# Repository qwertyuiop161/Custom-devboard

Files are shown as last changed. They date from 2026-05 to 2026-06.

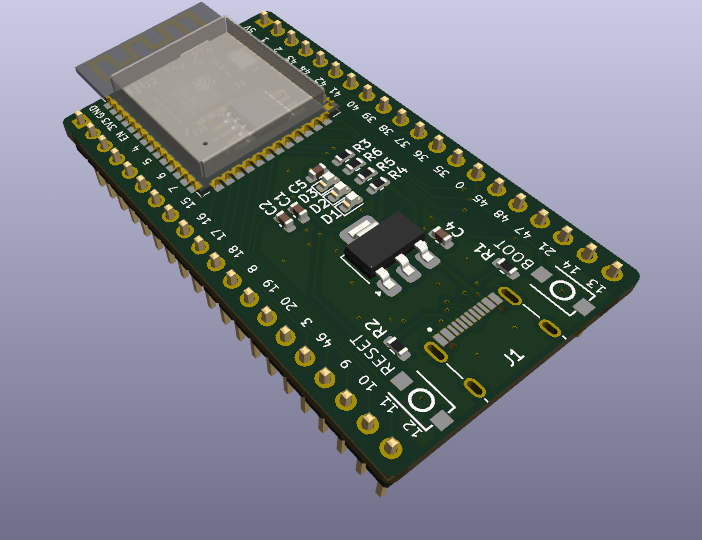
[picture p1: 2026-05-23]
images/3d model front.png

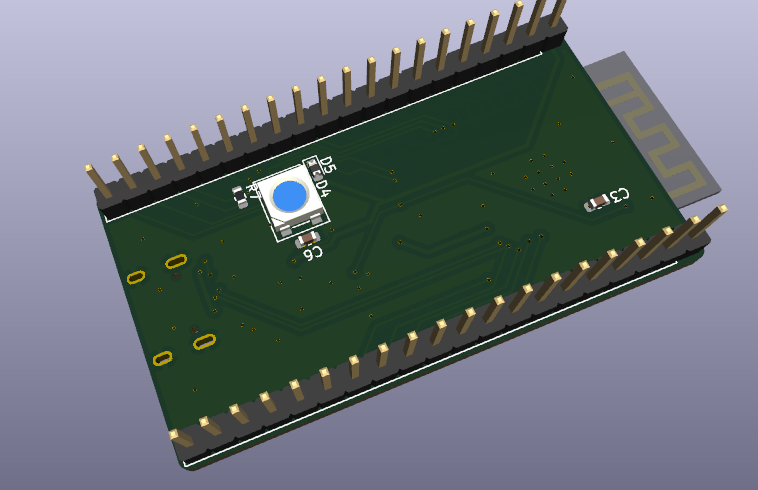
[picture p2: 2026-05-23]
images/3d model back.png

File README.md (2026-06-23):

##Description

This is a custom devboard made with an ESP32-S3-WROOM-1 module using the preinstalled firmware. It uses a usb controller and a usb C port, with 5 main capacitors and 6 main resistors, along with 3 leds. the back (because im not good enough to have it all one sided YET (still learning (wow double paren (WOW QUAD PAREN)))) hsa an addressable LES with 2 more resistors and another capacitors.
I choose the ESP chip because of its power compared to arduino, WIFI and bluetooth capability, ease of wiring, and use of use. It has 40 pins, with 30 usable GPIO i think; also just wanted to mention that semicolon was a typo its just kinda funna that im so used to java and C that i accidentally end every sentence in typing with semicolon (even accidentally did iton this before correcting).

##Images:

###Schematic image:

Image of schematic:
<br>

schematic

###PCB images:

PCB full
<br>

pcb full

PCB pads and zones
<br>

pcb pads and zones

PCB tracks and vias
<br>

pcb tracks and vias

###3D Model images:

3D model front
<br>

3d model front

3D model back
<br>

3d model back

###BOM image:

BOM
<br>



###Bult Board:

Built Board! (sorry for low quality I have a bad camera):

WIN_20260622_18_30_54_Pro

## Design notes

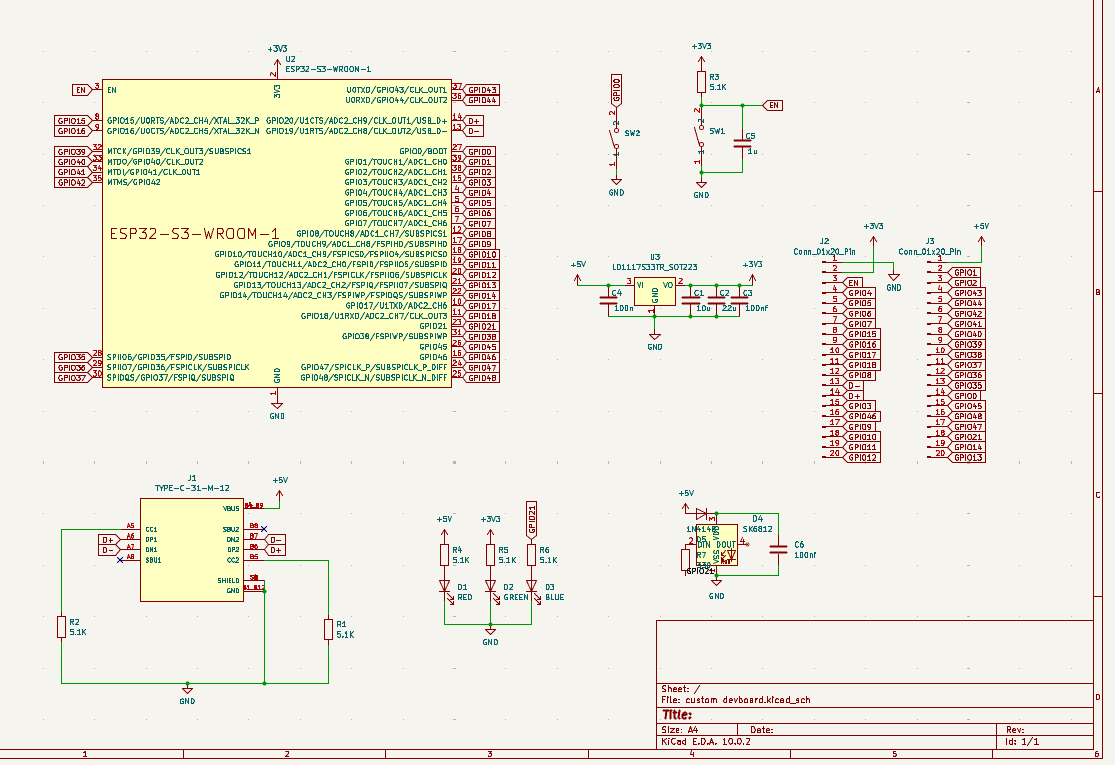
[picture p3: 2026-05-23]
images/schematic.png

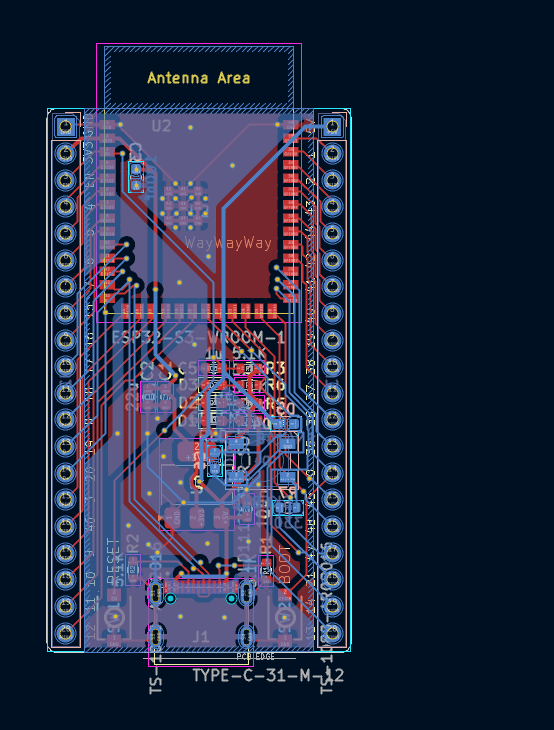
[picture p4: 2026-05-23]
images/pcb full.png

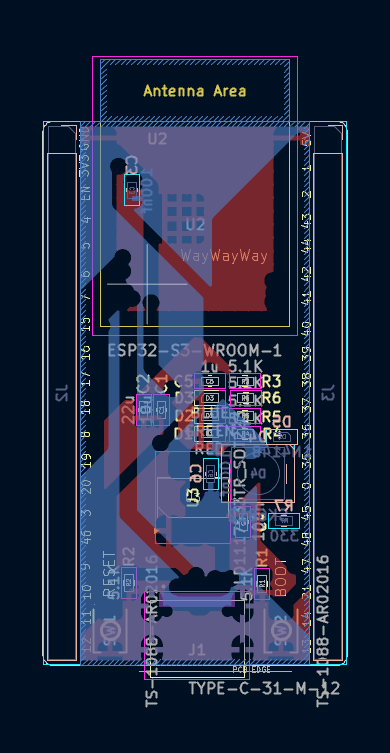
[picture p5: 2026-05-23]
images/pcb pads and zones.png

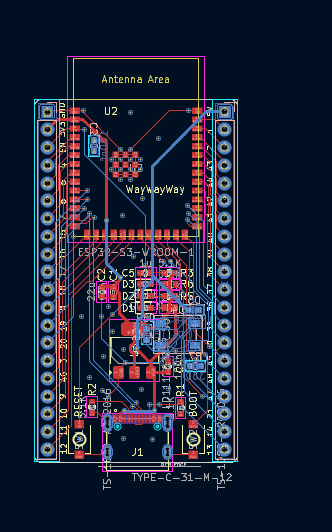
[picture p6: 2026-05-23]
images/pcb tracks and vias.png

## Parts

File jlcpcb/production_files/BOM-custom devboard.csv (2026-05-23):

Comment | Designator | Footprint | LCSC | Quantity
100n | C4 | C_0603_1608Metric | C14663 | 1
100nf | C3,C6 | C_0603_1608Metric | C1591 | 2
10u | C1 | C_0603_1608Metric | C19702 | 1
1N4148 | D5 | D_0603_1608Metric | C2972761 | 1
1u | C5 | C_0603_1608Metric | C14664 | 1
22u | C2 | C_0603_1608Metric | C2762594 | 1
330 | R7 | R_0603_1608Metric | C105881 | 1
5.1K | R1,R2,R3,R4,R5,R6 | R_0603_1608Metric | C105580 | 6
BLUE | D3 | LED_0603_1608Metric | C72041 | 1
Conn_01x20_Pin | J2,J3 | PinHeader_1x20_P2.54mm_Vertical | C7501591 | 2
ESP32-S3-WROOM-1 | U2 | ESP32-S3-WROOM-1 | C2913202 | 1
GREEN | D2 | LED_0603_1608Metric | C72043 | 1
LD1117S33TR_SOT223 | U3 | SOT-223-3_TabPin2 | C86781 | 1
RED | D1 | LED_0603_1608Metric | C2286 | 1
SK6812 | D4 | LED_SK6812_PLCC4_5.0x5.0mm_P3.2mm | C5378720 | 1
TS-1088-AR02016 | SW1,SW2 | SW-SMD_L3.9-W3.0-P4.45 | C720477 | 2
TYPE-C-31-M-12 | J1 | HRO_TYPE-C-31-M-12 | C165948 | 1

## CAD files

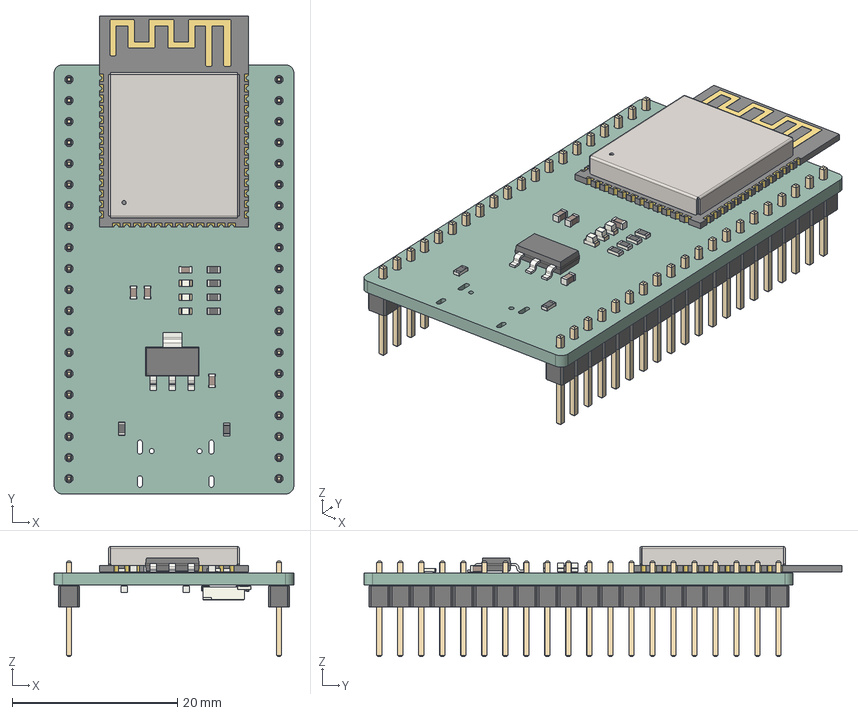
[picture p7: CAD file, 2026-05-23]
schematic and pcb and 3d model/3d.step
29.0 x 57.8 x 13.3 mm
R_0603_1608Metric x 7
LED_0603_1608Metric x 3
SOT-223
C_0603_1608Metric x 6
C0201_20210301.STEP^C0201_20210301.STEP_Submodel-C0201_part_ DesignRootModel_PCB_ESP32-S3-WROOM-1_V1(2)_PCB_ESP32-S3-WROOM-1_V1 x 14
L0201_20210301.STEP^L0201_20210301.STEP_Submodel-L0201_part_ DesignRootModel_PCB_ESP32-S3-WROOM-1_V1(2)_PCB_ESP32-S3-WROOM-1_V1 x 3
C0402_20210301.STEP^C0402_20210301.STEP_Submodel-C0402_part_ DesignRootModel_PCB_ESP32-S3-WROOM-1_V1(2)_PCB_ESP32-S3-WROOM-1_V1
R0201_20210301.STEP^R0201_20210301.STEP_Submodel-R0201_part_ DesignRootModel_PCB_ESP32-S3-WROOM-1_V1(2)_PCB_ESP32-S3-WROOM-1_V1 x 8
trace_1^Submodel-MINI-ANT-TYPEB_668419613_part_DesignRootModel_PCB_ ESP32-S3-WROOM-1_V1(2)_PCB_ESP32-S3-WROOM-1_V1
DFN1006.STEP^DFN1006.STEP_Submodel-SOD882_part_DesignRootModel_PCB_ ESP32-S3-WROOM-1_V1(2)_PCB_ESP32-S3-WROOM-1_V1
SOP8_rev1_20210308.STEP^SOP8_rev1_20210308.STEP_Submodel-SOP8_1P27_6P6_ part_DesignRootModel_PCB_ESP32-S3-WROOM-1_V1(2)_PCB_ESP32-S3-WROOM-1_V1
XTAL3225_20210301.STEP^XTAL3225_20210301.STEP_Submodel-XTAL3225_part_ DesignRootModel_PCB_ESP32-S3-WROOM-1_V1(2)_PCB_ESP32-S3-WROOM-1_V1
ESP32-S3_20210301.STEP^ESP32-S3_20210301.STEP_Submodel-QFN56_0P4_7_ part_DesignRootModel_PCB_ESP32-S3-WROOM-1_V1(2)_PCB_ESP32-S3-WROOM-1_V1
uid__4-128^DesignRootModel_PCB_ESP32-S3-WROOM-1_V1(2)_PCB_ ESP32-S3-WROOM-1_V1
uid__4-129^DesignRootModel_PCB_ESP32-S3-WROOM-1_V1(2)_PCB_ ESP32-S3-WROOM-1_V1
uid__4-130^DesignRootModel_PCB_ESP32-S3-WROOM-1_V1(2)_PCB_ ESP32-S3-WROOM-1_V1
uid__4-149^DesignRootModel_PCB_ESP32-S3-WROOM-1_V1(2)_PCB_ ESP32-S3-WROOM-1_V1
uid__4-150^DesignRootModel_PCB_ESP32-S3-WROOM-1_V1(2)_PCB_ ESP32-S3-WROOM-1_V1
uid__4-151^DesignRootModel_PCB_ESP32-S3-WROOM-1_V1(2)_PCB_ ESP32-S3-WROOM-1_V1
uid__4-167^DesignRootModel_PCB_ESP32-S3-WROOM-1_V1(2)_PCB_ ESP32-S3-WROOM-1_V1
uid__4-168^DesignRootModel_PCB_ESP32-S3-WROOM-1_V1(2)_PCB_ ESP32-S3-WROOM-1_V1
uid__4-169^DesignRootModel_PCB_ESP32-S3-WROOM-1_V1(2)_PCB_ ESP32-S3-WROOM-1_V1
uid__1-279^DesignRootModel_PCB_ESP32-S3-WROOM-1_V1(2)_PCB_ ESP32-S3-WROOM-1_V1
uid__1-280^DesignRootModel_PCB_ESP32-S3-WROOM-1_V1(2)_PCB_ ESP32-S3-WROOM-1_V1
uid__1-292^DesignRootModel_PCB_ESP32-S3-WROOM-1_V1(2)_PCB_ ESP32-S3-WROOM-1_V1
uid__1-298^DesignRootModel_PCB_ESP32-S3-WROOM-1_V1(2)_PCB_ ESP32-S3-WROOM-1_V1
uid__1-299^DesignRootModel_PCB_ESP32-S3-WROOM-1_V1(2)_PCB_ ESP32-S3-WROOM-1_V1
uid__1-300^DesignRootModel_PCB_ESP32-S3-WROOM-1_V1(2)_PCB_ ESP32-S3-WROOM-1_V1
uid__1-301^DesignRootModel_PCB_ESP32-S3-WROOM-1_V1(2)_PCB_ ESP32-S3-WROOM-1_V1
uid__1-304^DesignRootModel_PCB_ESP32-S3-WROOM-1_V1(2)_PCB_ ESP32-S3-WROOM-1_V1
uid__1-305^DesignRootModel_PCB_ESP32-S3-WROOM-1_V1(2)_PCB_ ESP32-S3-WROOM-1_V1
uid__1-308^DesignRootModel_PCB_ESP32-S3-WROOM-1_V1(2)_PCB_ ESP32-S3-WROOM-1_V1
uid__1-310^DesignRootModel_PCB_ESP32-S3-WROOM-1_V1(2)_PCB_ ESP32-S3-WROOM-1_V1
uid__1-311^DesignRootModel_PCB_ESP32-S3-WROOM-1_V1(2)_PCB_ ESP32-S3-WROOM-1_V1
uid__1-325^DesignRootModel_PCB_ESP32-S3-WROOM-1_V1(2)_PCB_ ESP32-S3-WROOM-1_V1
uid__1-334^DesignRootModel_PCB_ESP32-S3-WROOM-1_V1(2)_PCB_ ESP32-S3-WROOM-1_V1
uid__1-338^DesignRootModel_PCB_ESP32-S3-WROOM-1_V1(2)_PCB_ ESP32-S3-WROOM-1_V1
uid__1-339^DesignRootModel_PCB_ESP32-S3-WROOM-1_V1(2)_PCB_ ESP32-S3-WROOM-1_V1
uid__1-340^DesignRootModel_PCB_ESP32-S3-WROOM-1_V1(2)_PCB_ ESP32-S3-WROOM-1_V1
uid__1-343^DesignRootModel_PCB_ESP32-S3-WROOM-1_V1(2)_PCB_ ESP32-S3-WROOM-1_V1
uid__1-344^DesignRootModel_PCB_ESP32-S3-WROOM-1_V1(2)_PCB_ ESP32-S3-WROOM-1_V1
uid__1-345^DesignRootModel_PCB_ESP32-S3-WROOM-1_V1(2)_PCB_ ESP32-S3-WROOM-1_V1
uid__1-352^DesignRootModel_PCB_ESP32-S3-WROOM-1_V1(2)_PCB_ ESP32-S3-WROOM-1_V1
uid__1-354^DesignRootModel_PCB_ESP32-S3-WROOM-1_V1(2)_PCB_ ESP32-S3-WROOM-1_V1
uid__1-355^DesignRootModel_PCB_ESP32-S3-WROOM-1_V1(2)_PCB_ ESP32-S3-WROOM-1_V1
uid__1-357^DesignRootModel_PCB_ESP32-S3-WROOM-1_V1(2)_PCB_ ESP32-S3-WROOM-1_V1
uid__1-358^DesignRootModel_PCB_ESP32-S3-WROOM-1_V1(2)_PCB_ ESP32-S3-WROOM-1_V1
uid__1-359^DesignRootModel_PCB_ESP32-S3-WROOM-1_V1(2)_PCB_ ESP32-S3-WROOM-1_V1
uid__1-364^DesignRootModel_PCB_ESP32-S3-WROOM-1_V1(2)_PCB_ ESP32-S3-WROOM-1_V1
uid__1-365^DesignRootModel_PCB_ESP32-S3-WROOM-1_V1(2)_PCB_ ESP32-S3-WROOM-1_V1
uid__1-371^DesignRootModel_PCB_ESP32-S3-WROOM-1_V1(2)_PCB_ ESP32-S3-WROOM-1_V1
uid__1-375^DesignRootModel_PCB_ESP32-S3-WROOM-1_V1(2)_PCB_ ESP32-S3-WROOM-1_V1
uid__1-376^DesignRootModel_PCB_ESP32-S3-WROOM-1_V1(2)_PCB_ ESP32-S3-WROOM-1_V1
uid__1-378^DesignRootModel_PCB_ESP32-S3-WROOM-1_V1(2)_PCB_ ESP32-S3-WROOM-1_V1
uid__1-379^DesignRootModel_PCB_ESP32-S3-WROOM-1_V1(2)_PCB_ ESP32-S3-WROOM-1_V1
uid__1-380^DesignRootModel_PCB_ESP32-S3-WROOM-1_V1(2)_PCB_ ESP32-S3-WROOM-1_V1
uid__1-381^DesignRootModel_PCB_ESP32-S3-WROOM-1_V1(2)_PCB_ ESP32-S3-WROOM-1_V1
uid__1-382^DesignRootModel_PCB_ESP32-S3-WROOM-1_V1(2)_PCB_ ESP32-S3-WROOM-1_V1
uid__1-383^DesignRootModel_PCB_ESP32-S3-WROOM-1_V1(2)_PCB_ ESP32-S3-WROOM-1_V1
uid__1-384^DesignRootModel_PCB_ESP32-S3-WROOM-1_V1(2)_PCB_ ESP32-S3-WROOM-1_V1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

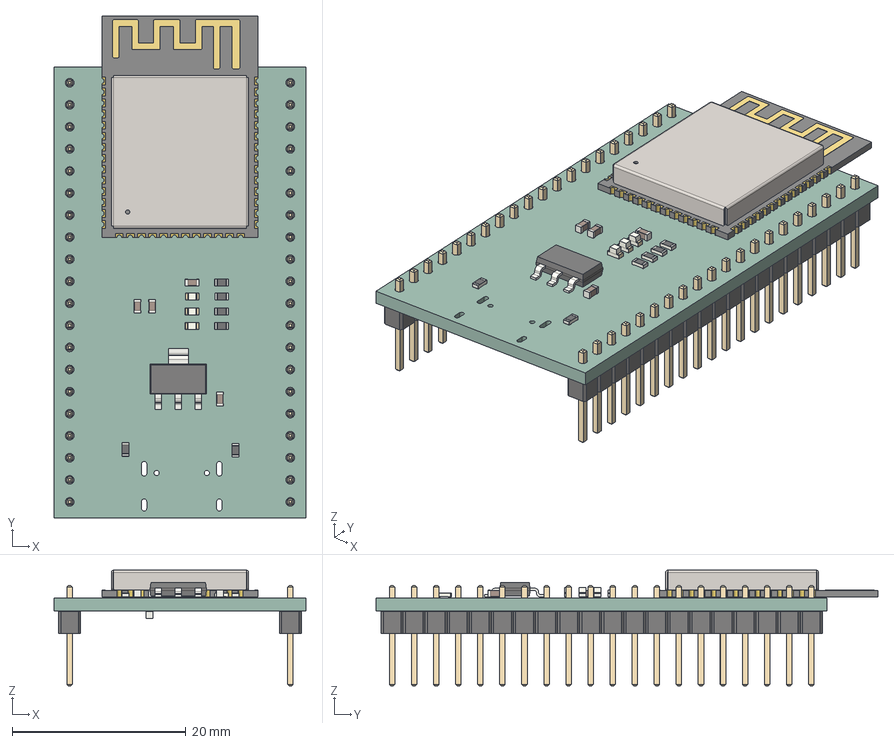
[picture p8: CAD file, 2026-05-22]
schematic and pcb and 3d model/custom devboard.step
29.0 x 57.8 x 13.3 mm
R_0603_1608Metric x 6
LED_0603_1608Metric x 3
SOT-223
C_0603_1608Metric x 5
C0201_20210301.STEP^C0201_20210301.STEP_Submodel-C0201_part_ DesignRootModel_PCB_ESP32-S3-WROOM-1_V1(2)_PCB_ESP32-S3-WROOM-1_V1 x 14
L0201_20210301.STEP^L0201_20210301.STEP_Submodel-L0201_part_ DesignRootModel_PCB_ESP32-S3-WROOM-1_V1(2)_PCB_ESP32-S3-WROOM-1_V1 x 3
C0402_20210301.STEP^C0402_20210301.STEP_Submodel-C0402_part_ DesignRootModel_PCB_ESP32-S3-WROOM-1_V1(2)_PCB_ESP32-S3-WROOM-1_V1
R0201_20210301.STEP^R0201_20210301.STEP_Submodel-R0201_part_ DesignRootModel_PCB_ESP32-S3-WROOM-1_V1(2)_PCB_ESP32-S3-WROOM-1_V1 x 8
trace_1^Submodel-MINI-ANT-TYPEB_668419613_part_DesignRootModel_PCB_ ESP32-S3-WROOM-1_V1(2)_PCB_ESP32-S3-WROOM-1_V1
DFN1006.STEP^DFN1006.STEP_Submodel-SOD882_part_DesignRootModel_PCB_ ESP32-S3-WROOM-1_V1(2)_PCB_ESP32-S3-WROOM-1_V1
SOP8_rev1_20210308.STEP^SOP8_rev1_20210308.STEP_Submodel-SOP8_1P27_6P6_ part_DesignRootModel_PCB_ESP32-S3-WROOM-1_V1(2)_PCB_ESP32-S3-WROOM-1_V1
XTAL3225_20210301.STEP^XTAL3225_20210301.STEP_Submodel-XTAL3225_part_ DesignRootModel_PCB_ESP32-S3-WROOM-1_V1(2)_PCB_ESP32-S3-WROOM-1_V1
ESP32-S3_20210301.STEP^ESP32-S3_20210301.STEP_Submodel-QFN56_0P4_7_ part_DesignRootModel_PCB_ESP32-S3-WROOM-1_V1(2)_PCB_ESP32-S3-WROOM-1_V1
uid__4-128^DesignRootModel_PCB_ESP32-S3-WROOM-1_V1(2)_PCB_ ESP32-S3-WROOM-1_V1
uid__4-129^DesignRootModel_PCB_ESP32-S3-WROOM-1_V1(2)_PCB_ ESP32-S3-WROOM-1_V1
uid__4-130^DesignRootModel_PCB_ESP32-S3-WROOM-1_V1(2)_PCB_ ESP32-S3-WROOM-1_V1
uid__4-149^DesignRootModel_PCB_ESP32-S3-WROOM-1_V1(2)_PCB_ ESP32-S3-WROOM-1_V1
uid__4-150^DesignRootModel_PCB_ESP32-S3-WROOM-1_V1(2)_PCB_ ESP32-S3-WROOM-1_V1
uid__4-151^DesignRootModel_PCB_ESP32-S3-WROOM-1_V1(2)_PCB_ ESP32-S3-WROOM-1_V1
uid__4-167^DesignRootModel_PCB_ESP32-S3-WROOM-1_V1(2)_PCB_ ESP32-S3-WROOM-1_V1
uid__4-168^DesignRootModel_PCB_ESP32-S3-WROOM-1_V1(2)_PCB_ ESP32-S3-WROOM-1_V1
uid__4-169^DesignRootModel_PCB_ESP32-S3-WROOM-1_V1(2)_PCB_ ESP32-S3-WROOM-1_V1
uid__1-279^DesignRootModel_PCB_ESP32-S3-WROOM-1_V1(2)_PCB_ ESP32-S3-WROOM-1_V1
uid__1-280^DesignRootModel_PCB_ESP32-S3-WROOM-1_V1(2)_PCB_ ESP32-S3-WROOM-1_V1
uid__1-292^DesignRootModel_PCB_ESP32-S3-WROOM-1_V1(2)_PCB_ ESP32-S3-WROOM-1_V1
uid__1-298^DesignRootModel_PCB_ESP32-S3-WROOM-1_V1(2)_PCB_ ESP32-S3-WROOM-1_V1
uid__1-299^DesignRootModel_PCB_ESP32-S3-WROOM-1_V1(2)_PCB_ ESP32-S3-WROOM-1_V1
uid__1-300^DesignRootModel_PCB_ESP32-S3-WROOM-1_V1(2)_PCB_ ESP32-S3-WROOM-1_V1
uid__1-301^DesignRootModel_PCB_ESP32-S3-WROOM-1_V1(2)_PCB_ ESP32-S3-WROOM-1_V1
uid__1-304^DesignRootModel_PCB_ESP32-S3-WROOM-1_V1(2)_PCB_ ESP32-S3-WROOM-1_V1
uid__1-305^DesignRootModel_PCB_ESP32-S3-WROOM-1_V1(2)_PCB_ ESP32-S3-WROOM-1_V1
uid__1-308^DesignRootModel_PCB_ESP32-S3-WROOM-1_V1(2)_PCB_ ESP32-S3-WROOM-1_V1
uid__1-310^DesignRootModel_PCB_ESP32-S3-WROOM-1_V1(2)_PCB_ ESP32-S3-WROOM-1_V1
uid__1-311^DesignRootModel_PCB_ESP32-S3-WROOM-1_V1(2)_PCB_ ESP32-S3-WROOM-1_V1
uid__1-325^DesignRootModel_PCB_ESP32-S3-WROOM-1_V1(2)_PCB_ ESP32-S3-WROOM-1_V1
uid__1-334^DesignRootModel_PCB_ESP32-S3-WROOM-1_V1(2)_PCB_ ESP32-S3-WROOM-1_V1
uid__1-338^DesignRootModel_PCB_ESP32-S3-WROOM-1_V1(2)_PCB_ ESP32-S3-WROOM-1_V1
uid__1-339^DesignRootModel_PCB_ESP32-S3-WROOM-1_V1(2)_PCB_ ESP32-S3-WROOM-1_V1
uid__1-340^DesignRootModel_PCB_ESP32-S3-WROOM-1_V1(2)_PCB_ ESP32-S3-WROOM-1_V1
uid__1-343^DesignRootModel_PCB_ESP32-S3-WROOM-1_V1(2)_PCB_ ESP32-S3-WROOM-1_V1
uid__1-344^DesignRootModel_PCB_ESP32-S3-WROOM-1_V1(2)_PCB_ ESP32-S3-WROOM-1_V1
uid__1-345^DesignRootModel_PCB_ESP32-S3-WROOM-1_V1(2)_PCB_ ESP32-S3-WROOM-1_V1
uid__1-352^DesignRootModel_PCB_ESP32-S3-WROOM-1_V1(2)_PCB_ ESP32-S3-WROOM-1_V1
uid__1-354^DesignRootModel_PCB_ESP32-S3-WROOM-1_V1(2)_PCB_ ESP32-S3-WROOM-1_V1
uid__1-355^DesignRootModel_PCB_ESP32-S3-WROOM-1_V1(2)_PCB_ ESP32-S3-WROOM-1_V1
uid__1-357^DesignRootModel_PCB_ESP32-S3-WROOM-1_V1(2)_PCB_ ESP32-S3-WROOM-1_V1
uid__1-358^DesignRootModel_PCB_ESP32-S3-WROOM-1_V1(2)_PCB_ ESP32-S3-WROOM-1_V1
uid__1-359^DesignRootModel_PCB_ESP32-S3-WROOM-1_V1(2)_PCB_ ESP32-S3-WROOM-1_V1
uid__1-364^DesignRootModel_PCB_ESP32-S3-WROOM-1_V1(2)_PCB_ ESP32-S3-WROOM-1_V1
uid__1-365^DesignRootModel_PCB_ESP32-S3-WROOM-1_V1(2)_PCB_ ESP32-S3-WROOM-1_V1
uid__1-371^DesignRootModel_PCB_ESP32-S3-WROOM-1_V1(2)_PCB_ ESP32-S3-WROOM-1_V1
uid__1-375^DesignRootModel_PCB_ESP32-S3-WROOM-1_V1(2)_PCB_ ESP32-S3-WROOM-1_V1
uid__1-376^DesignRootModel_PCB_ESP32-S3-WROOM-1_V1(2)_PCB_ ESP32-S3-WROOM-1_V1
uid__1-378^DesignRootModel_PCB_ESP32-S3-WROOM-1_V1(2)_PCB_ ESP32-S3-WROOM-1_V1
uid__1-379^DesignRootModel_PCB_ESP32-S3-WROOM-1_V1(2)_PCB_ ESP32-S3-WROOM-1_V1
uid__1-380^DesignRootModel_PCB_ESP32-S3-WROOM-1_V1(2)_PCB_ ESP32-S3-WROOM-1_V1
uid__1-381^DesignRootModel_PCB_ESP32-S3-WROOM-1_V1(2)_PCB_ ESP32-S3-WROOM-1_V1
uid__1-382^DesignRootModel_PCB_ESP32-S3-WROOM-1_V1(2)_PCB_ ESP32-S3-WROOM-1_V1
uid__1-383^DesignRootModel_PCB_ESP32-S3-WROOM-1_V1(2)_PCB_ ESP32-S3-WROOM-1_V1
uid__1-384^DesignRootModel_PCB_ESP32-S3-WROOM-1_V1(2)_PCB_ ESP32-S3-WROOM-1_V1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

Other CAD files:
schematic and pcb and 3d model/3d.stl

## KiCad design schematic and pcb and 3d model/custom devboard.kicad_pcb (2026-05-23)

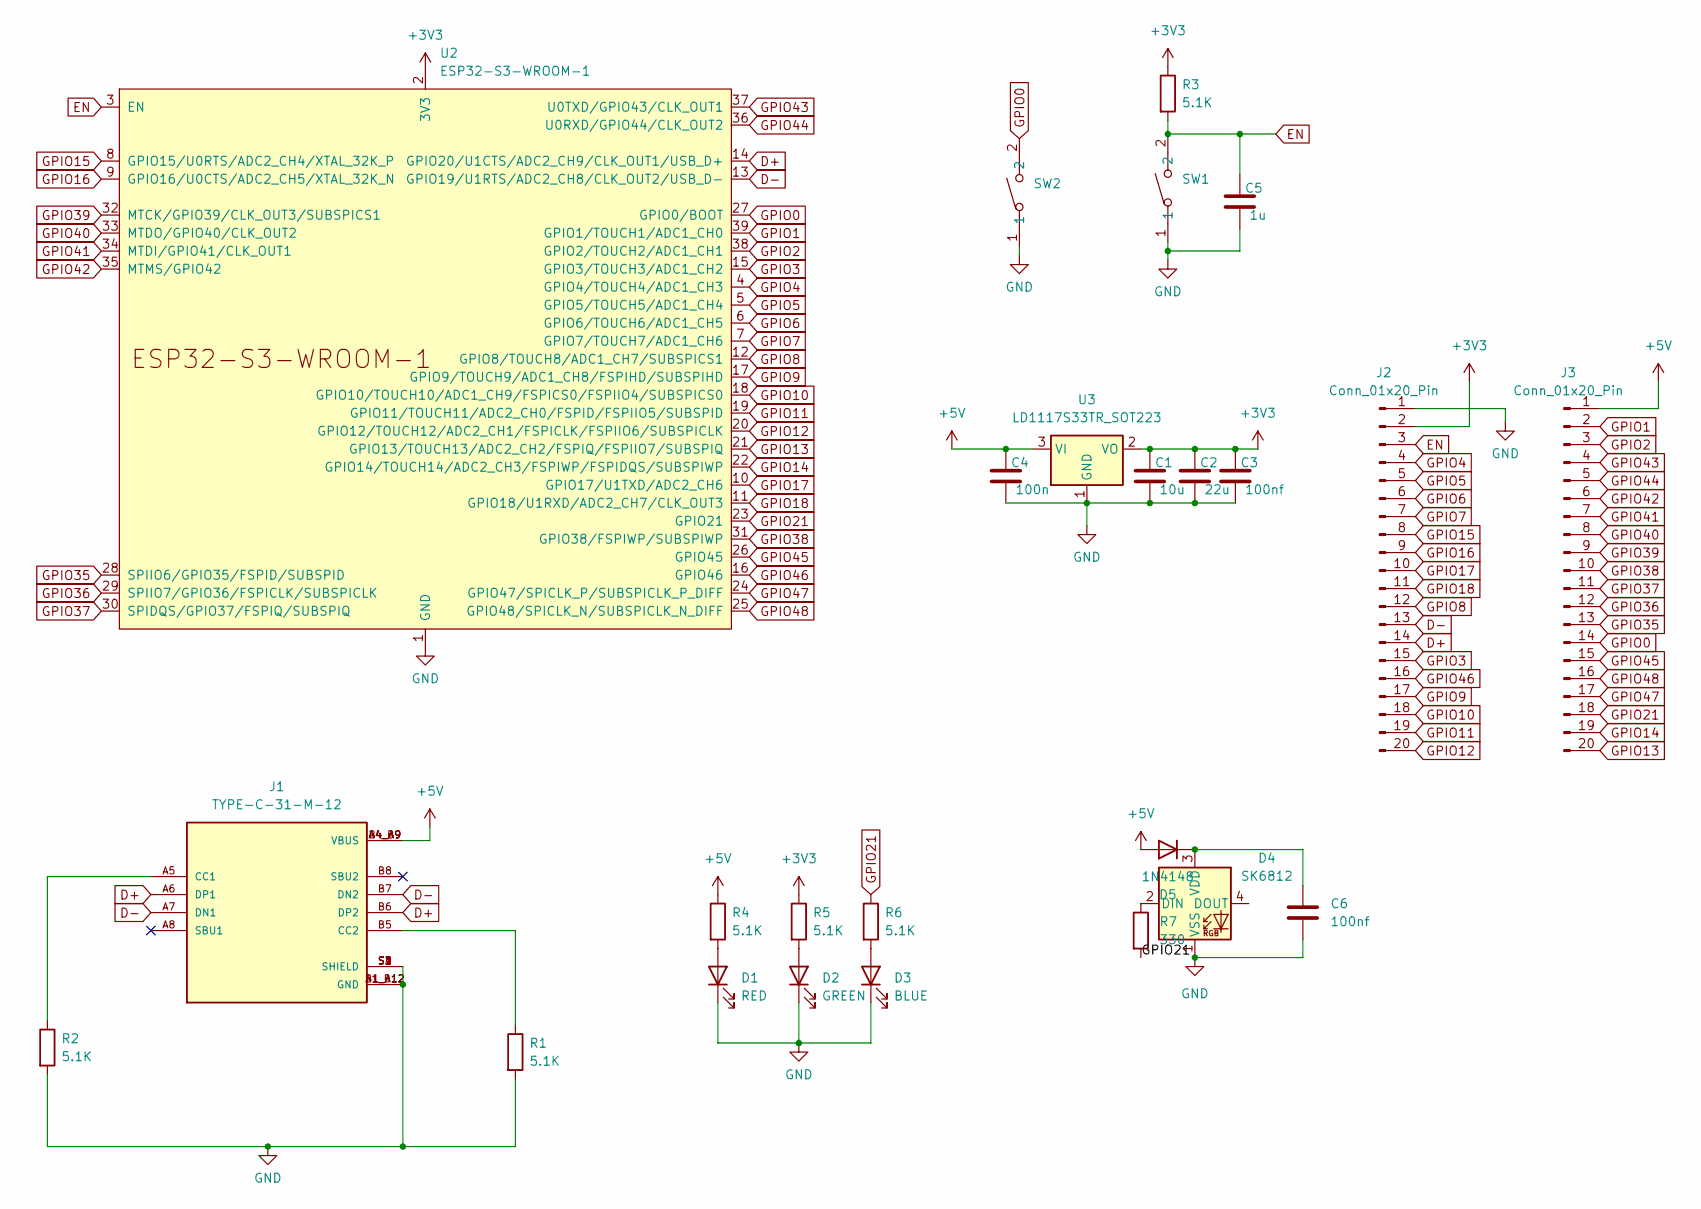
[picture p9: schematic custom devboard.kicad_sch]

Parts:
C1: 10u; C_0603_1608Metric
C2: 22u; C_0603_1608Metric
C3, C6: 100nf; C_0603_1608Metric
C4: 100n; C_0603_1608Metric
C5: 1u; C_0603_1608Metric
D1: RED; LED_0603_1608Metric
D2: GREEN; LED_0603_1608Metric
D3: BLUE; LED_0603_1608Metric
D4: SK6812; LED_SK6812_PLCC4_5.0x5.0mm_P3.2mm
D5: 1N4148; D_0603_1608Metric
J1: TYPE-C-31-M-12; HRO_TYPE-C-31-M-12; PARTREV 2020.12.08
J2, J3: Conn_01x20_Pin; PinHeader_1x20_P2.54mm_Vertical
R1, R2, R3, R4, R5, R6: 5.1K; R_0603_1608Metric
R7: 330; R_0603_1608Metric
SW1, SW2: TS-1088-AR02016; SW-SMD_L3.9-W3.0-P4.45; LCSC Part C720477
U2: ESP32-S3-WROOM-1
U3: LD1117S33TR_SOT223; SOT-223-3_TabPin2

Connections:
+3V3: C1.1, C2.1, C3.1, J2.2, R3.1, R5.1, U2.2 (3V3), U3.2 (VO)
+5V: C4.1, D5.2 (A), J1.A4_B9 (VBUS), J1.B4_A9 (VBUS), J3.1, R4.1, U3.3 (VI)
D+: J1.A6 (DP1), J1.B6 (DP2), J2.14, U2.14 (GPIO20/U1CTS/ADC2_CH9/CLK_OUT1/USB_D+)
D-: J1.A7 (DN1), J1.B7 (DN2), J2.13, U2.13 (GPIO19/U1RTS/ADC2_CH8/CLK_OUT2/USB_D-)
EN: C5.1, J2.3, R3.2, SW1.2, U2.3 (EN)
GND: C1.2, C2.2, C3.2, C4.2, C5.2, C6.2, D1.1 (K), D2.1 (K), D3.1 (K), D4.1 (VSS), J1.A1_B12 (GND), J1.B1_A12 (GND), J1.S1 (SHIELD), J1.S2 (SHIELD), J1.S3 (SHIELD), J1.S4 (SHIELD), J2.1, R1.2, R2.2, SW1.1, SW2.1, U2.1 (GND), U2.40 (GND), U2.41 (GND), U3.1 (GND)
GPIO0: J3.14, SW2.2, U2.27 (GPIO0/BOOT)
GPIO1: J3.2, U2.39 (GPIO1/TOUCH1/ADC1_CH0)
GPIO2: J3.3, U2.38 (GPIO2/TOUCH2/ADC1_CH1)
GPIO3: J2.15, U2.15 (GPIO3/TOUCH3/ADC1_CH2)
GPIO4: J2.4, U2.4 (GPIO4/TOUCH4/ADC1_CH3)
GPIO5: J2.5, U2.5 (GPIO5/TOUCH5/ADC1_CH4)
GPIO6: J2.6, U2.6 (GPIO6/TOUCH6/ADC1_CH5)
GPIO7: J2.7, U2.7 (GPIO7/TOUCH7/ADC1_CH6)
GPIO8: J2.12, U2.12 (GPIO8/TOUCH8/ADC1_CH7/SUBSPICS1)
GPIO9: J2.17, U2.17 (GPIO9/TOUCH9/ADC1_CH8/FSPIHD/SUBSPIHD)
GPIO10: J2.18, U2.18 (GPIO10/TOUCH10/ADC1_CH9/FSPICS0/FSPIIO4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)
GPIO11: J2.19, U2.19 (GPIO11/TOUCH11/ADC2_CH0/FSPID/FSPIIO5/S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)
GPIO12: J2.20, U2.20 (GPIO12/TOUCH12/ADC2_CH1/FSPICLK/FSPIIO6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)
GPIO13: J3.20, U2.21 (GPIO13/TOUCH13/ADC2_CH2/FSPIQ/FSPIIO7/S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)
GPIO14: J3.19, U2.22 (GPIO14/TOUCH14/ADC2_CH3/FSPIWP/FSPIDQS/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)
GPIO15: J2.8, U2.8 (GPIO15/U0RTS/ADC2_CH4/XTAL_32K_P)
GPIO16: J2.9, U2.9 (GPIO16/U0CTS/ADC2_CH5/XTAL_32K_N)
GPIO17: J2.10, U2.10 (GPIO17/U1TXD/ADC2_CH6)
GPIO18: J2.11, U2.11 (GPIO18/U1RXD/ADC2_CH7/CLK_OUT3)
GPIO21: J3.18, R6.1, R7.2, U2.23 (GPIO21)
GPIO35: J3.13, U2.28 (SPIIO6/GPIO35/FSPID/SUBSPID)
GPIO36: J3.12, U2.29 (SPIIO7/GPIO36/FSPICLK/SUBSPICLK)
GPIO37: J3.11, U2.30 (SPIDQS/GPIO37/FSPIQ/SUBSPIQ)
GPIO38: J3.10, U2.31 (GPIO38/FSPIWP/SUBSPIWP)
GPIO39: J3.9, U2.32 (MTCK/GPIO39/CLK_OUT3/SUBSPICS1)
GPIO40: J3.8, U2.33 (MTDO/GPIO40/CLK_OUT2)
GPIO41: J3.7, U2.34 (MTDI/GPIO41/CLK_OUT1)
GPIO42: J3.6, U2.35 (MTMS/GPIO42)
GPIO43: J3.4, U2.37 (U0TXD/GPIO43/CLK_OUT1)
GPIO44: J3.5, U2.36 (U0RXD/GPIO44/CLK_OUT2)
GPIO45: J3.15, U2.26 (GPIO45)
GPIO46: J2.16, U2.16 (GPIO46)
GPIO47: J3.17, U2.24 (GPIO47/SPICLK_P/SUBSPICLK_P_DIFF)
GPIO48: J3.16, U2.25 (GPIO48/SPICLK_N/SUBSPICLK_N_DIFF)
unnamed: D1.2 (A), R4.2
unnamed: D2.2 (A), R5.2
unnamed: D3.2 (A), R6.2
unnamed: D4.2 (DIN), R7.1
unnamed: C6.1, D4.3 (VDD), D5.1 (K)
unnamed: J1.A5 (CC1), R2.1
unnamed: J1.B5 (CC2), R1.1

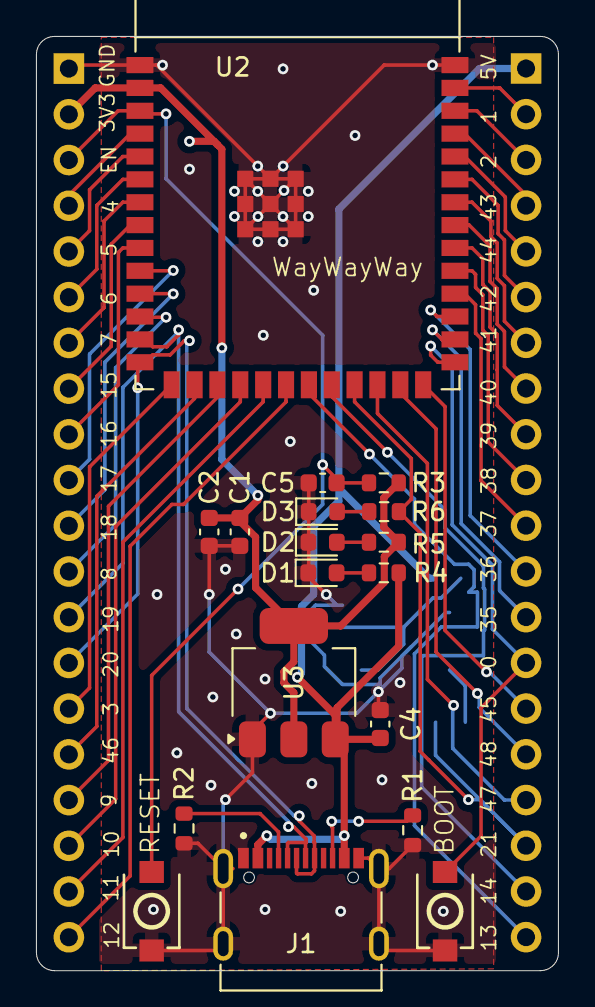
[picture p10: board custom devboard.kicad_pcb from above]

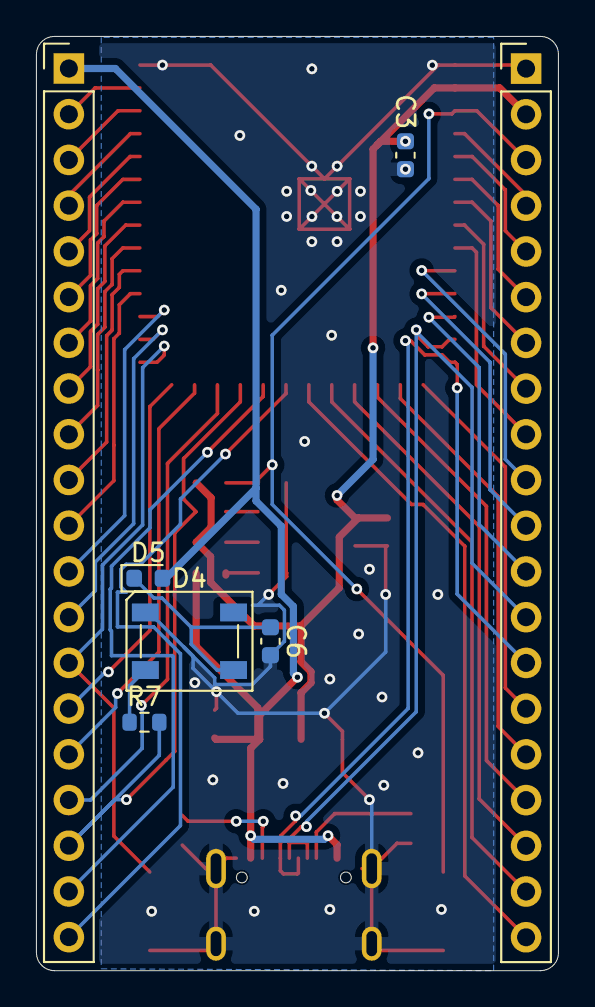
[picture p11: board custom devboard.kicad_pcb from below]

Board: 2 copper layers, 29.0 x 51.9 mm, 25 parts (7 on the bottom side), 47 nets.

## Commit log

2026-05-17 Enhance README with project details
    Updated project description to provide more context about the PCB design and its purpose.
2026-05-23 Enhance README with PCB design details and images
    Added additional information about the PCB design, including images of the schematic, PCB layouts, and a 3D model.
2026-05-23 Fix formatting and add new images in README
    Updated formatting for schematic, PCB, and model sections.
2026-05-23 Add README content for custom devboard
    Added detailed description of the custom devboard, including specifications, images, and links to schematics.
2026-06-01 Revise README formatting and add images
    Updated section headers and added images for schematic, PCB, 3D model, and BOM.
